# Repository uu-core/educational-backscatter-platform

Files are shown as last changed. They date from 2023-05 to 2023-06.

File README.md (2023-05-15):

# Pico-Backscatter
An educational project on backscatter using Raspberry Pi Pico

## Repo Organization
- `hardware` contains the hardware design with further description and explanation (generating the PIO using the python script).
- `project_pico_libs` contains the libs for all projects using the RPI Pico (carrier/receiver/baseband).
- `baseband` contains a 2-FSK baseband code using Pico PIO together with a generator script, its description and some exercise questions.
- `carrier-CC2500` contains a carrier generator using the Mikroe-1435 (CC2500) on the Pico.
- `receiver-CC2500` contains a receiver using the Mikroe-1435 (CC2500) on the Pico.
- `carrier-Firefly` contains the configuration guidance for home setup with zolertia firefly as carrier.
- `carrier-characteristics` contains a measurement to estimate the typical carrier bandwidth.
- `carrier_receiver-CC1352` contains the configuration guidance for lab setup with CC1352 as carrier and/or receiver.
- `carrier-receiver-baseband` integrates all components into one setup: the Pico generates the baseband, uses one Mikroe-1435 (CC2500) to generate a carrier and a second Mikroe-1435 (CC2500) to receive the backscattered signal.
- `stats` contains the system evaluation script.

## Installation
A number of pre-requisites are needed to work with this repo:
Raspberry Pi Pico SDK, cmake and arm-none-eabi-gcc have to be installed for building and flashing the application code.
<br>Please follow the installation guidance in [Getting started with Rasberry Pi Pico](https://datasheets.raspberrypi.com/pico/getting-started-with-pico.pdf).
<br>Using Visual Studio Code is recommended.

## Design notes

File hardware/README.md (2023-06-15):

# Pico-Backscatter: frontend
The implementation for the backscatter tag frontend on a four-layer FR4 PCB with 1oz copper thickness and a spacing of 0.2mm between the top and first inner layer for 50 ohm impedance matching.

### Usage notes
- The board can be used with the Maker Pi Pico (bottom connectors) or the Raspberry Pi Pico (top connectors). _Do not connect a RPI Pico and Maker Pi Pico at the same time._
- For power measurements, a power profiler can be connected to J5. Remember that the board should not be powered by two sources at the same time. Therefore, _unplug the USB from the RPI Pico before using an external power supply, such as a power profiler_. Just in case that two supplies get connected at the same time, they are be protected by a schottky diode. Therefore the board is supplied with about 0.25V less than provided (the voltage drop can be avoided by: supplying the voltage directly to the VSYS pin rather than J5, which avoids the diode and is therefore unprotected. Another alternative is to replace the diode with a mosfet in standard reverse voltage protection configuration).
- The board provides an interface to four SMA connectors for backscattering signals. This enables the use of antenna arrays and the resulting directivity/gain of different configurations can be generated using [Matlab's Antenna array design tool](https://se.mathworks.com/help/antenna/gs/design-and-analysis-using-antenna-array-designer-app.html).
- The board provides two connections for the ccRF click boards (Mikroe-1435 with the CC2500). They can be used as carrier generator and receiver.
- Notice that you can simulate a larger distance to the carrier by decreasing the transmission power in a static setup.

### Technical notes
- Each antenna is connected to an open or closed circuit based on a signal of the RPI Pico. This results in a reflection coefficient of +1 or -1, such that the incoming signal is always fully reflected either in phase (0°) or inverted (at 180° phase). In the time domain, we can think of this as taking the carrier and multiplying it with a sequence of +1/-1, which is equivalent to a convolution in the frequency domain and can therefore be used as modulation.
- Consider an ambient carrier signal $f_c$ and the RPI Pico generating a baseband signal $f_b$, which controls the antenna switch. The backscattered signal will then be $f_{s} = f_c + f_b$. Since we have control of $f_b$, we can use $f_s$ directly to generate a Frequency-Shift Keying (FSK) or On-Off Keying (OOK). Since additionally the phase of the carrier is static, the phase of the backscattered signal $f_s$ is equal to the phase of the baseband signal $f_b$. This can be used to generate a Phase-Shift Keying (PSK). For example, increasing the frequency of $f_b$ by 1 MHz and changing its phase by 90°, will also change the frequency and phase of the backscattered signal $f_s$ by 1 MHz and phase of 90°. Finally, due to the spectrum of a sinus, we obtain a second (mirrored) image of $f_s$ at $f_m = f_c - f_b$ which we can ignore for now. Since the baseband signal is also a square-wave and not a sinus, the backscattered signal will have harmonic overtones above $f_s$ and below $f_m$, which we can also ignore for now. However, you can find the mirrored image on the spectrum analyzer and also the overtones at a sufficiently large Signal-to-Noise ratio (SNR).
- The switch that controls the antenna termination could be implemented with a simple MOSFET. However, using an RF-switch provides a better impedance matching and control. Therefore, this platform uses the design of Ambuj Varshney and uses the [HMC190BMS8E](https://www.analog.com/media/en/technical-documentation/data-sheets/hmc190b.pdf). RF-switches can be categorized into having reflective (open circuit) or absorptive ($50 \Omega$ matching) inputs while not being selected to connect to the output. The HMC190BMS8E is a reflective RF-switch. Therefore, we can connect the antenna to its _input_. While the antenna is not selected as input, the RF-switch represents an open circuit (reflection coefficient +1). Now, we can terminate the output of the RF-switch directly to ground to generate the short circuit (reflection coefficient -1). The baseband signal of the RPI Pico controls if the antenna input connects to the output of the RF-switch or not and therefore changes the reflection coefficient at the antenna as described above between +1/-1.

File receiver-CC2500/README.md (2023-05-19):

# Pico-Backscatter: receiver-CC2500

### Decription
Receiver example using the Mikroe-1435 (CC2500) on the Pico.
The stdout (printf) has been directed to USB.

## Backscatter Tag Configuration
Please change the Macro variable RECEIVER to 2500.

### Radio wiring information

The example here uses SPI 0.

   * GPIO 17 (pin 22) Chip select
   * GPIO 18 (pin 24) SCK/spi0_sclk
   * GPIO 19 (pin 25) MOSI/spi0_tx
   * GPIO 21 GDO0: interrupt for received sync word

### Receiver configuration

The CC2500 can transmit and receive arbitrarily long packets. However, is FIFO is limited to 64 byte, out of which 4 byte are occupied by the length-field, sequence number and link quality information. This leaves 60 bytes for the payload.

To transmit larger payloads, it would be necessary to continoulsy empty the fifo while receiving a packet which can lead to unwanted and timing dependent byte duplications as highlighted in the [datasheet errata](https://www.ti.com/lit/er/swrz002e/swrz002e.pdf).

### Radio Settings
The radio settings and configuration can be generated using [SmartRF Studio](https://www.ti.com/tool/SMARTRFTM-STUDIO) and the datasheet of the corresponding module. Notice that the the configured baudrate of the Pico may be imprecise and differ from the one that the radio should be using. To export the register settings compatible with the provided examples, you can add a new template with the following settings (Register Export -> New ->):
- Header
    ```
    #ifndef RF_SETTING
    #define RF_SETTING
    struct rf_setting {
        uint8_t address;
        uint8_t  value;
    };
    typedef struct rf_setting RF_setting;
    #endif

    RF_setting radio_settings[] = {
    ```
- Body:
    ```
        {.address = 0x@ah@,@<<@ .value = 0x@VH@}, // @CHIPID@_@RN@: @Rd@
    ```
- Footer `};`

Additionally, notice that the exported register configuration of SmartRF Studio does not contain the transmission power setting, which is configured in the PA-Table.

### Build the project
Please follow the installation guidance in [Getting started with Raspberry Pi Pico](https://datasheets.raspberrypi.com/pico/getting-started-with-pico.pdf).

For **Linux and MacOS**:
1. set the sdk path {the path} with the absolute path\
```
 export PICO_SDK_PATH={the path}/pico-sdk
```
2. create build folder
```
mkdir build && cd build
```
3. prepare cmake build directory by running
```
cmake ..
```
4. build project
```
make
```

For **Windows**:
1. set the sdk path {the path} with the absolute path\
```
 setx PICO_SDK_PATH "{the path}/pico-sdk"
```
2. create build folder
```
mkdir build
cd build
```
3. prepare cmake build directory by running
```
cmake -G "NMake Makefiles" ..
nmake
```

## Reference
[Raspberry Pi Pico SDK Libraries and tools for C/C++ development on RP2040 microcontrollers](https://datasheets.raspberrypi.com/pico/raspberry-pi-pico-c-sdk.pdf).
<br>The details about PIO, please refer to [RP2040 Datasheet](https://datasheets.raspberrypi.com/rp2040/rp2040-datasheet.pdf).

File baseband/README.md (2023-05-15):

# Pico-Backscatter: baseband
The implementation for backscatter tag onboard control unit to generate an information-bearing 2-FSK signal using Raspberry Pi Pico PIO.
The stdout (printf) has been directed to USB.

## Repo Organization
- `generate-backscatter-pio.py` provides a script to generate a PIO file for the desired shift frequencies and baud-rate.
- `backscatter.pio` provides an example output of `generate-backscatter-pio.py`
- `backscatter.c` contains an example of generating a pseudorandom payload and using the generated backscatter driver
- `CMakeList.txt`

## Frame Structure
| Header {10B} | Random Payload {Max. 60B} |
<br>**Header structure**
<br>| Preamble {4B} | SYNC words {4B} | Frame length {1B} | Sequence number {1B} |
<br> **RX: CC2500**
<br> | 0xaa 0xaa 0xaa 0xaa | 0xd3 0x91 0xd3 0x91 | 0x00 | 0x00 |
<br> **RX: CC1312**
<br> | 0xaa 0xaa 0xaa 0xaa | 0x93 0x0b 0x51 0xde | 0x00 | 0x00 |
<br> Please change the Macro variable RECEIVER, depending on your receiver setup.
<br>**Random Payload structure**
<br>| Pseudo sequence {2B} | random number {Max. 58B, which is equal to 29*(16-bit random number)}

## Usage of the PIO generation script

The PIO file is generated based on two clock-dividers from 125 MHz and a baud-rate. Each clock divider provides a frequency offset from the carrier for one symbol. The script prints the required radio settings in terms of the resulting center frequency offset and frequency deviation.
- Help: `python generate-backscatter-pio.py --help`
- Generating a PIO file: `python generate-backscatter-pio.py clock-divider-Symbol-0 clock-divider-Symbol-1 baud-rate output-file`

Example: `python generate-backscatter-pio.py 20 18 100000 ./backscatter.pio`
- 20     => 125MHz/20 = 6.25 MHz frequency offset from carrier for symbol 0
- 18     => 125MHz/18 = 6.94 MHz frequency offset from carrier for symbol 1
- 100000 => 100 kBaud
- notice that the output file has to match with the `CMakeLists.txt`

## Exercises questions
1. Why shall be used only _even_ clock dividers for generating the baseband?
2. How do the two frequency dividers and the baudrate affect the signal-to-noise ratio (SNR)? To maximize the SNR, how should the frequency deviation be? How should the baudrate be? How should the frequency offset be (remember its relation to $N_0$ due to the self-interference)?
3. What is the relation between the two clock dividers to achieve the best possible deviation for a given offset frequency? This relation leaves one degree of freedom. Generate a table which provides the achievable offset frequencies (center) together with the most desirable frequency deviation.
5. Question 2 highlighted a trade-off and question 3 highlighted a dependence. Create a simulation to identify the ideal trade-off parameter (table from question 3) for a given baudrate. How dependent are your results on the assumed distances and carrier?
Notice that you know the worst case baseband spectrum from the baudrate, can estimate the carrier spectrum using the measurements in `carrier-characteristics` and can take reasonable assumptions for the path-loss model and RX filter response.
6. Generate an experimental setup to estimate remaining parameters and calibrate the simulation.
7. Knowing the SNR at the receiver, the used signal bandwidth and assuming an additive white Gaussian noise (AWGN) channel: What is the *channel capacity* of your occupied resources based on the Shannon–Hartley theorem?
8. Assume you would like to optimize your parameters to maximize the channel capacity. Do you come to the same conclusion like for optimizing the SNR? Why/Why not?

### Antenna characteristics:
- the provided antennas are [Molex 2128601001](https://www.molex.com/molex/products/part-detail/antennas/2128601001)
- a quick guide of trace antennas can be found [here](https://www.ti.com/lit/an/swra351b/swra351b.pdf), which provides links to the most commen pcb antennas such as the [SWRA117 and its characteristics](https://www.ti.com/lit/an/swra117d/swra117d.pdf).

## Build the project
For **Linux and MacOS**:
1. set the sdk path {the path} with the absolute path\
```
 export PICO_SDK_PATH={the path}/pico-sdk
```
2. create build folder
```
mkdir build && cd build
```
3. prepare cmake build directory by running
```
cmake ..
```
4. build project
```
make
```

For **Windows**:
1. set the sdk path {the path} with the absolute path\
```
 setx PICO_SDK_PATH "{the path}/pico-sdk"
```
2. create build folder
```
mkdir build && cd build
```
3. prepare cmake build directory by running
```
cmake -G "NMake Makefiles" ..
nmake
```

## Reference
[Raspberry Pi Pico SDK Libraries and tools for C/C++ development on RP2040 microcontrollers](https://datasheets.raspberrypi.com/pico/raspberry-pi-pico-c-sdk.pdf).
<br>The details about PIO, please refer to [RP2040 Datasheet](https://datasheets.raspberrypi.com/rp2040/rp2040-datasheet.pdf).

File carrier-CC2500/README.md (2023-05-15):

# Pico-Backscatter: carrier-CC2500
### Decription
Carrier generator using the Mikroe-1435 (CC2500) on the Pico.
The stdout (printf) has been directed to USB.
The carrier is configured for 2450 MHz by default.

### Radio wiring information

The example here uses SPI 0.

   * GPIO  5 Chip select
   * GPIO 18 SCK/spi0_sclk
   * GPIO 19 MOSI/spi0_tx

### Radio Settings
The radio settings and configuration can be generated using [SmartRF Studio](https://www.ti.com/tool/SMARTRFTM-STUDIO) and the datasheet of the corresponding module.
<br>Notice that the the configured baudrate of the Pico may be imprecise and differ from the one that the radio should be using. <br>To export the register settings compatible with the provided examples, you can add a new template with the following settings (Register Export -> New ->):
- Header
    ```
    #ifndef RF_SETTING
    #define RF_SETTING
    struct rf_setting {
        uint8_t address;
        uint8_t  value;
    };
    typedef struct rf_setting RF_setting;
    #endif

    RF_setting radio_settings[] = {
    ```
- Body:
    ```
        {.address = 0x@ah@,@<<@ .value = 0x@VH@}, // @CHIPID@_@RN@: @Rd@
    ```
- Footer `};`

Additionally, notice that the exported register configuration of SmartRF Studio does not contain the transmission power setting, which is configured in the PA-Table.

### Build the project
Please follow the installation guidance in [Getting started with Raspberry Pi Pico](https://datasheets.raspberrypi.com/pico/getting-started-with-pico.pdf).

For **Linux and MacOS**:
1. set the sdk path {the path} with the absolute path\
```
 export PICO_SDK_PATH={the path}/pico-sdk
```
2. create build folder
```
mkdir build && cd build
```
3. prepare cmake build directory by running
```
cmake ..
```
4. build project
```
make
```

For **Windows**:
1. set the sdk path {the path} with the absolute path\
```
 setx PICO_SDK_PATH "{the path}/pico-sdk"
```
2. create build folder
```
mkdir build && cd build
```
3. prepare cmake build directory by running
```
cmake -G "NMake Makefiles" ..
nmake
```

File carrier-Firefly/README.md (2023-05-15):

# Pico-Backscatter: carrier-Firefly
Guide to configure Firefly to generate a unmodulated carrier in the range of 2394MHz to 2507MHz.

You will control the board via serial port.

## Access Serial Port
<br> Install the python pyserial library:
```
 pip install pyserial
```
<br> Find the connected device port under /dev. 

Firefly should be connected to a usb port. The port name that appears
in your OS is OS- and machine-specific, but
most likely starts with "tty.usb". One way is to 
disconnect and reconnect Firefly, and see the new name that appears.
```
ls /dev/
```
<br> Access the device via serial port:
```
python3 -m serial.tools.miniterm [your-port] 115200
```

## Configuration Option
After connecting with pyserial, it is possible that what you type in the 
console are invisible. They however should work after you press enter.

If the board does not respond to commands below, press reset button on Firefly
(you should see "hello world"). 

Configure the frequency
```
 f {frequency}
```
Start the carrier generation
```
 a
```
Reset the Firefly with reset button or the following command
```
 r
```

Example: set the carrier to 2450MHz
```
 f 2450
 a
```

## Reference
[Zolertia Firefly Datasheet](https://github.com/Zolertia/Resources/blob/master/Firefly/Hardware/Revision%20A/Datasheets/ZOL-BO001-A2%20-%20Firefly%20revision%20A%20Datasheet%20v.1.0.0.pdf)

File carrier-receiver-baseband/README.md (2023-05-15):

# Pico-Backscatter: carrier-receiver-backscatter (CC2500)
### Description
The implementation of a backscatter tag onboard control unit to generate an information-bearing 2-FSK signal using Raspberry Pi Pico PIO. The setup uses one Mikroe-1435 (CC2500) to generate a carrier and a second Mikroe-1435 (CC2500) to receive the backscattered signal.
The stdout (printf) has been directed to USB.

The example integrates the baseband, carrier generation and receiver. For further information on each component, please see the README files in:
- `baseband`
- `carrier-CC2500`
- `receiver-CC2500`

### Radio Settings
The radio settings and configuration can be generated using [SmartRF Studio](https://www.ti.com/tool/SMARTRFTM-STUDIO) and the datasheet of the corresponding module.
<br>Notice that the the configured baudrate of the Pico may be imprecise and differ from the one that the radio should be using. <br>To export the register settings compatible with the provided examples, you can add a new template with the following settings (Register Export -> New ->):
- Header
    ```
    #ifndef RF_SETTING
    #define RF_SETTING
    struct rf_setting {
        uint8_t address;
        uint8_t  value;
    };
    typedef struct rf_setting RF_setting;
    #endif

    RF_setting radio_settings[] = {
    ```
- Body:
    ```
        {.address = 0x@ah@,@<<@ .value = 0x@VH@}, // @CHIPID@_@RN@: @Rd@
    ```
- Footer `};`

Additionally, notice that the exported register configuration of SmartRF Studio does not contain the transmission power setting, which is configured in the PA-Table.

### Build the project
Please follow the installation guidance in [Getting started with Raspberry Pi Pico](https://datasheets.raspberrypi.com/pico/getting-started-with-pico.pdf).

For **Linux and MacOS**:
1. set the sdk path {the path} with the absolute path\
```
 export PICO_SDK_PATH={the path}/pico-sdk
```
2. create build folder
```
mkdir build && cd build
```
3. prepare cmake build directory by running
```
cmake ..
```
4. build project
```
make
```

For **Windows**:
1. set the sdk path {the path} with the absolute path\
```
 setx PICO_SDK_PATH "{the path}/pico-sdk"
```
2. create build folder
```
mkdir build && cd build
```
3. prepare cmake build directory by running
```
cmake -G "NMake Makefiles" ..
nmake
```

## Reference
[Raspberry Pi Pico SDK Libraries and tools for C/C++ development on RP2040 microcontrollers](https://datasheets.raspberrypi.com/pico/raspberry-pi-pico-c-sdk.pdf).
<br>The details about PIO, please refer to [RP2040 Datasheet](https://datasheets.raspberrypi.com/rp2040/rp2040-datasheet.pdf).

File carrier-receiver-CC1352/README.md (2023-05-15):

# Pico-Backscatter: carrier-receiver-CC1352
The configuration for Firefly to generate a unmodulated carrier in the range of 2394MHz to 2507MHz.
Control the launchpad via SmartRF studio.

## Installation
SmartRF™ Studio is a **Windows** application that helps designers of RF systems to easily evaluate the radio at an early stage in the design process for all TI CC1xxx and CC2xxx low-power RF devices.
<br> Please follow the installation guidance on Texas Instrument webpage [SmartRF Studio](https://www.ti.com/tool/SMARTRFTM-STUDIO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,stage%20in%20the%20design%20process.)

## Carrier
In the control panel, choose `Continuous TX`, `Unmodulated`, `Frequency`, `Transmission power 0dBm`
<br>Then click `Start`.

## Packet Receiver
In the control panel, choose `2.4G frequency band`, `Packet RX`
<br>`Base Freqeuncy`: $f_{R}$
<br>`Data Rate`: $R_{b}$
<br>`Deviation`: $\delta_{FSK}$
<br>`RX Filter BW`: $B_{R}$
<br>`Viewing Format` : Hexadecimal
<br>`Seq. Number Included in Payload`: uncheck
<br>`Length Config`: fixed (set the number based on the frame size configured on tag), or variable (use the length field to decide the frame length)
<br>Then click `Start`

## A screenshot of the SmartRF configuration as receiver
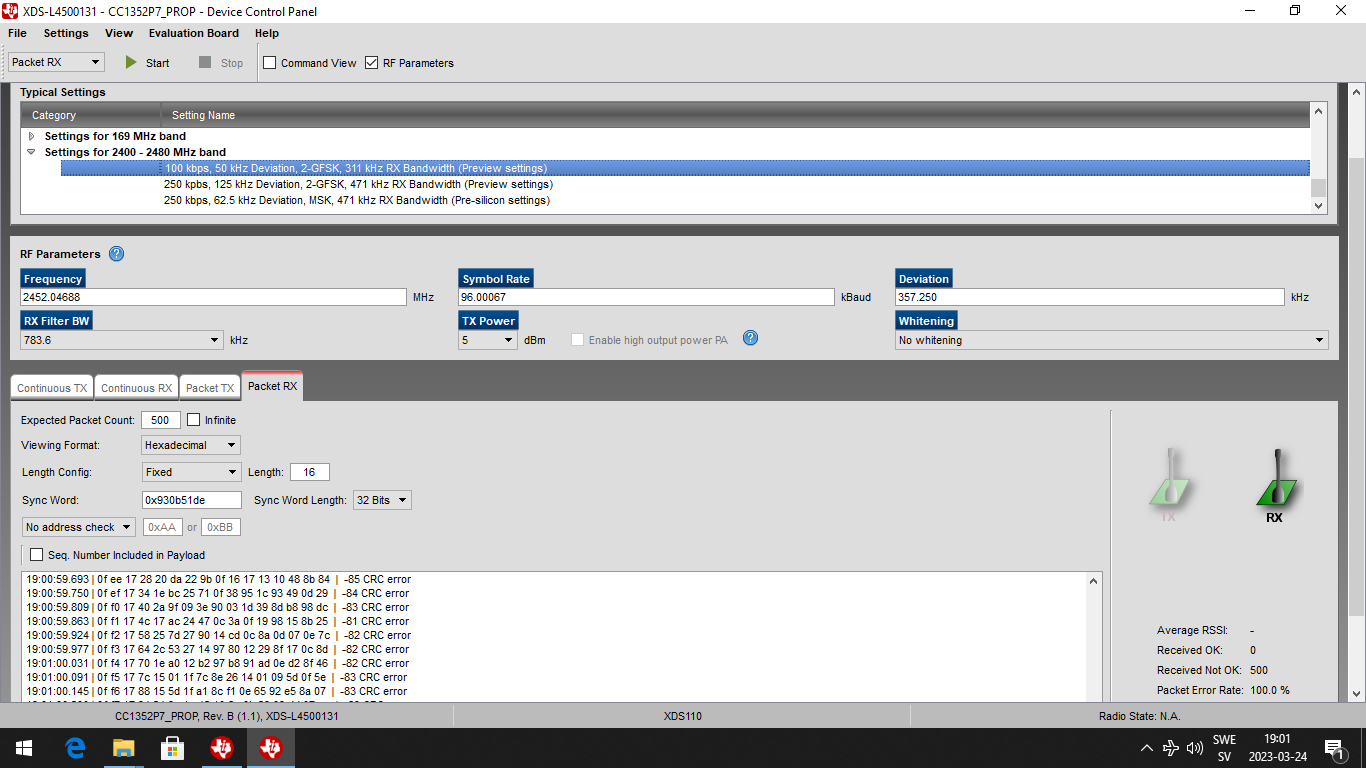
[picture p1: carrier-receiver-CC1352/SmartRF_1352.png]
plot

## Backscatter Tag Configuration
Please change the Macro variable RECEIVER to 1352.

## Reference
[CC1352P7 Datasheet](https://www.ti.com/product/CC1352P7)

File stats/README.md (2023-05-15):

# Pico-Backscatter: stats
A statistical analysis script evaluates communication system performance based on Jupyter Notebook.

## Evaluation metrics
- **Time**: the total latency that given amount of Data is delivered to the destination.
- **Reliability**: the ratio of data correctly delivered to the destination.
- **Distance Metric**: the communication distance of the system $D_{1}^2D_{2}^2$.

## Repo Organization
- `log.txt` contains log file received with either CC2500 or CC1352
- `functions.py` contains functions used in the analysis script
- `statistics.ipynb` contains the system evaluation script and visualisation script

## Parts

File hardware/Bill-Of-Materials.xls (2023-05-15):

Component | Order Qty. | Mouser No | Mfr. No | Manufacturer | Comment | Description
D1 | 1 | 863-MBR120VLSFT1G | MBR120VLSFT1G | onsemi | Polarity protection | Schottky Diodes & Rectifiers 1A 20V
C1-12 | 12 | 791-HH15N331F160CT | HH15N331F160CT | Walsin | RF Capacitors | Multilayer Ceramic Capacitors MLCC - SMD/SMT 0402 MLCC NPO 330 pF, +/- 1% 16 V T&R HH
J5 | 1 | 571-146280-2 | 146280-2 | TE Connectivity | - | Headers & Wire Housings 02 MODII HDR SRST B/A .100CL
U1-4 | 4 | 584-HMC190BMS8E | HMC190BMS8E | Analog Devices Inc. | - | RF Switch ICs Transmit/Receive (T/R) Switch, SPDT
R1-4 | 4 | 603-AT0402FRD071KL | AT0402FRD071KL | YAGEO | - | Thin Film Resistors - SMD 0402 1kOhms 1 % 25PPM 62.5mW AECQ200
AE1-4 | 4 | 710-60312002114503 | 60312002114503 | Wurth Elektronik | - | RF Connectors / Coaxial Connectors WR-SMA STRAIGHT JACK PCB THT
J1-4 | 4 | 200-SSM120FSV | SSM-120-F-SV | Samtec | Header Socket 1x20 SMD, 2.54mm pitch
J10-13 | 4 | 200-CES10801FS | CES-108-01-F-S | Samtec | Header Socket 1x08 Through Hole, 2.54mm pitch
J6-9 | - | (just drill holes) | - | - | - | -

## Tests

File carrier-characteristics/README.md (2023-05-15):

# Carrier characteristics

The provided images can be used to estimate the typical carrier bandwidth of the different nodes:
- the CC2500 was configured for a  $f_c=2450$ MHz carrier, had an error of $f_e = 0.12$ MHz and two side lobes at $\pm 1$ MHz. The combined bandwidth of all three lobes was ~2.5 MHz:
    - center: $(f_c + f_e)$ MHz
    - center bandwidth: ~1.078 MHz
    - right-lobe: $(f_c + f_e + 1)$ MHz
    - right-lobe bandwidth: ~0.520 MHz
    - left-lobe: $(f_c + f_e - 1)$ MHz
    - left-lobe bandwidth: ~0.520 MHz
- the CC1352P7 was configured for a $f_c=2455$ MHz carrier:
    - center: $f_c$ MHz
    - center bandwidth: ~1.158 MHz
- the Firefly was configured for a $f_c=2445$ MHz carrier
    - center: $f_c$ MHz
    - center bandwidth: ~0.918 MHz

## Center
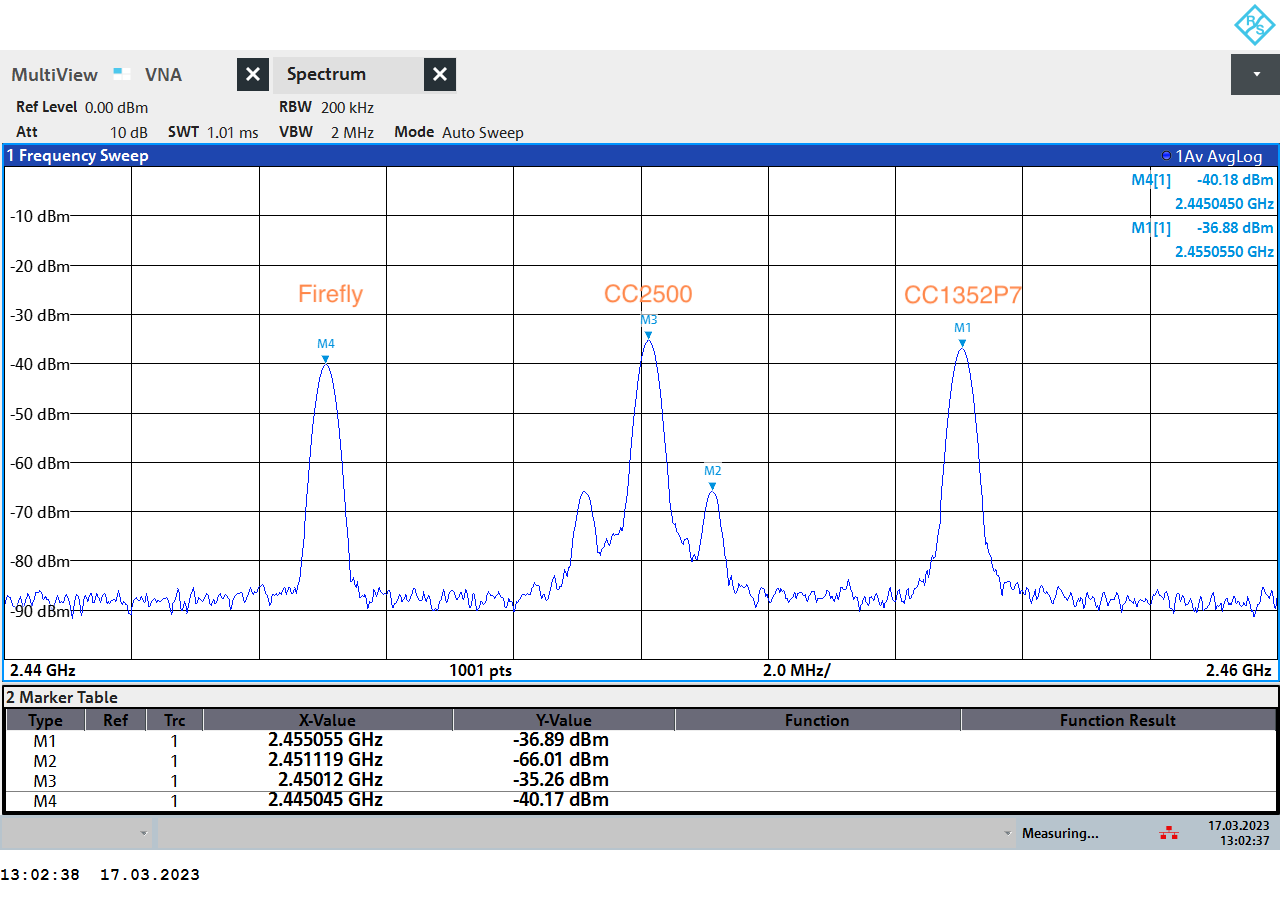
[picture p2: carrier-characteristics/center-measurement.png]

## Edge
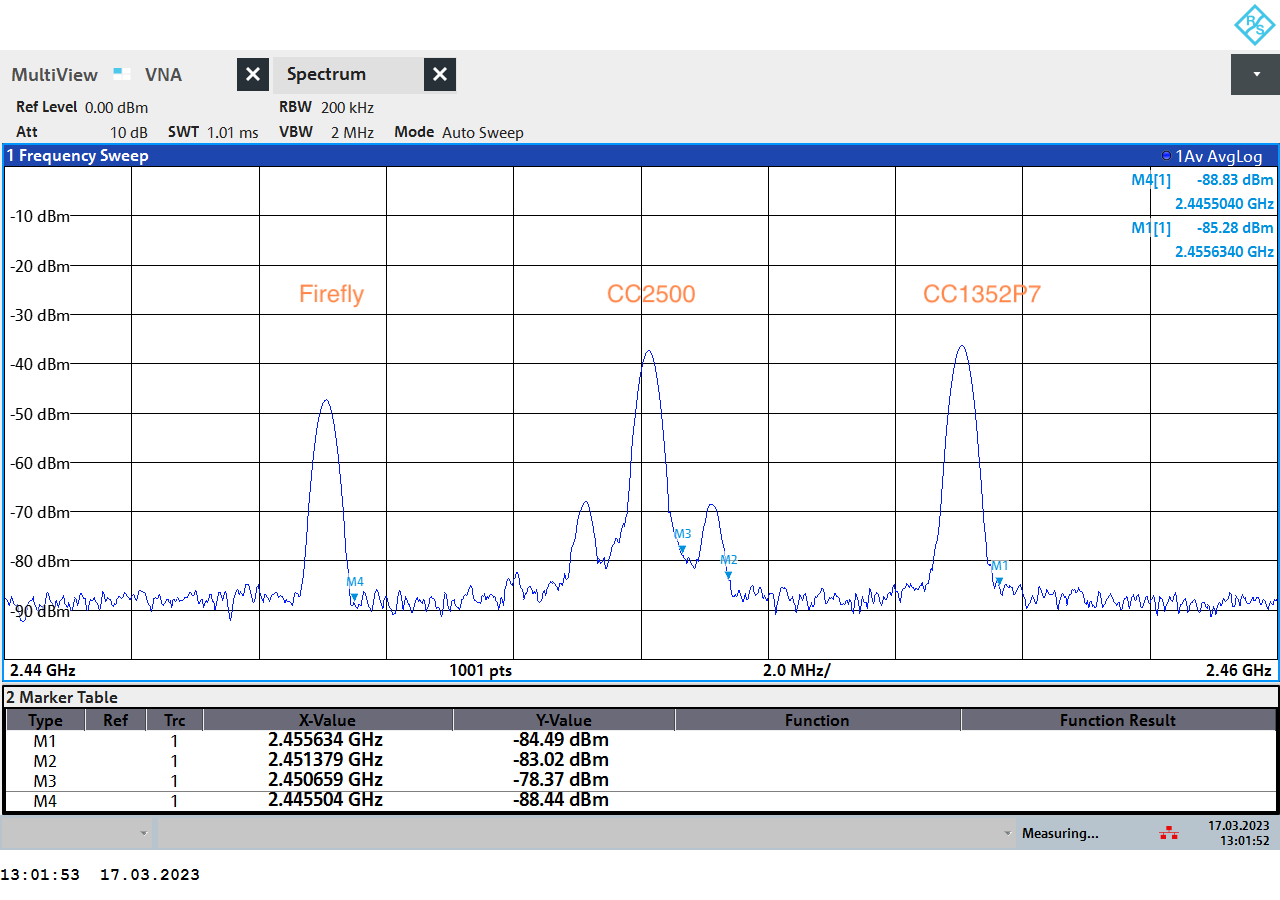
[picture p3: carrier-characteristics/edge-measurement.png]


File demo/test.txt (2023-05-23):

start listening
00:00:00.000 | 0f 00 a5 a5 a5 a5 a5 a5 a5 a5 a5 a5 a5 a5 a5 a5 | -62 CRC error 
00:00:01.000 | 0f 01 a5 a5 a5 a5 a5 a5 a5 a5 a5 a5 a5 a5 a5 a5 | -61 CRC error 
00:00:02.000 | 0f 02 a5 a5 a5 a5 a5 a5 a5 a5 a5 a5 a5 a5 a5 a5 | -61 CRC error 
00:00:03.000 | 0f 03 a5 a5 a5 a5 a5 a5 a5 a5 a5 a5 a5 a5 a5 a5 | -61 CRC error
00:00:04.000 | 0f 04 a5 a5 a5 a5 a5 a5 a5 a5 a5 a5 a5 a5 a5 a5 | -61 CRC error
00:00:05.000 | 0f 05 a5 a5 a5 a5 a5 a5 a5 a5 a5 a5 a5 a5 a5 a5 | -61 CRC error
00:00:06.000 | 01 01 a5 | -61 CRC error
00:00:07.000 | 0f 07 a5 a5 a5 a5 a5 a5 a5 a5 a5 a5 a5 a5 a5 a5 | -61 CRC error
00:00:08.000 | 0f 08 a5 a5 a5 a5 a5 a5 a5 a5 a5 a5 a5 a5 a5 a5 | -61 CRC error
00:00:09.000 | 0f 09 a5 a5 a5 a5 a5 a5 a5 a5 a5 a5 a5 a5 a5 a5 | -61 CRC error

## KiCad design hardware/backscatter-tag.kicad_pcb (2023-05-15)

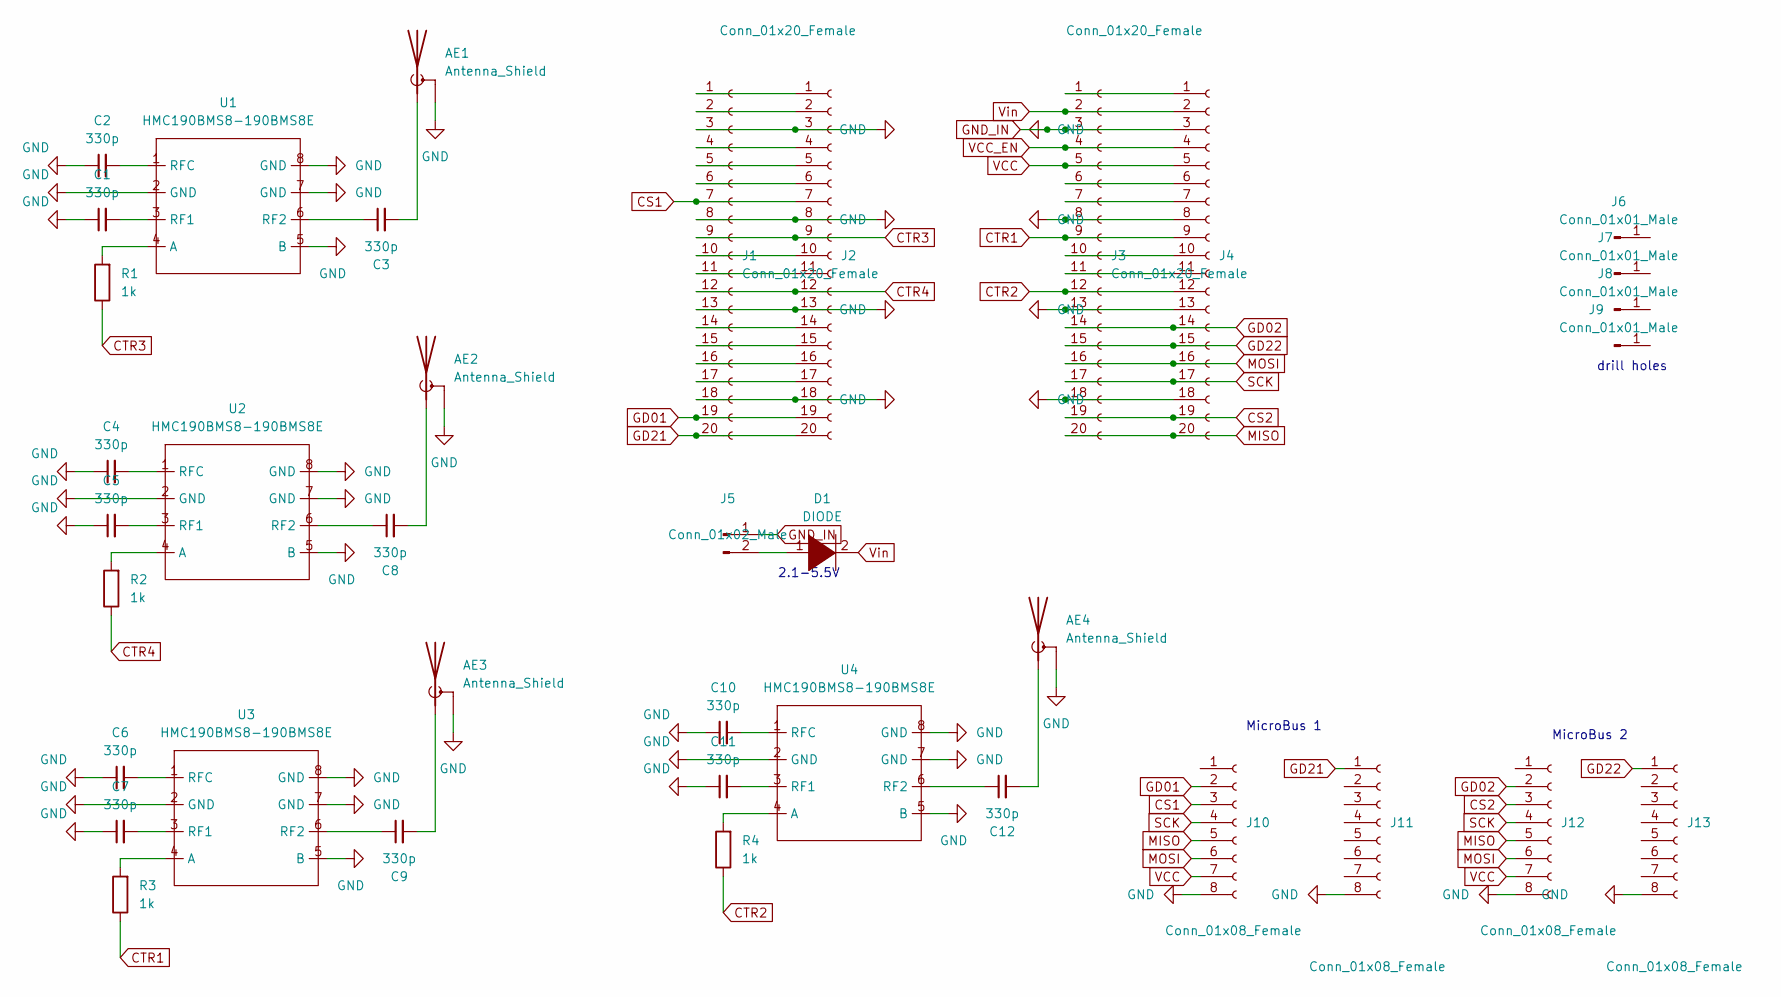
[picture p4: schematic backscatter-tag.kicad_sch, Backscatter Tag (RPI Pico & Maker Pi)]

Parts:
AE1, AE2, AE3, AE4: Antenna_Shield; SMA-60312002114503
C1, C2, C3, C4, C5, C6, C7, C8, C9, C10, C11, C12: 330p; C_0402_1005Metric
D1: DIODE; SOD-123FL-2
J1, J2, J3, J4: Conn_01x20_Female; PinSocket_1x20_P2.54mm_Vertical_SMD_Pin1Left
J5: Conn_01x02_Male; PinHeader_1x02_P2.54mm_Vertical
J6, J7, J8, J9: Conn_01x01_Male; mounting-whole
J10, J11, J12, J13: Conn_01x08_Female; PinSocket_1x08_P2.54mm_Vertical
R1, R2, R3, R4: 1k; R_0402_1005Metric
U1, U2, U3, U4: HMC190BMS8-190BMS8E; MSOP8

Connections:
CS1: J1.7, J2.7, J10.3
CS2: J3.19, J4.19, J12.3
CTR1: J3.9, J4.9, R3.1
CTR2: J3.12, J4.12, R4.1
CTR3: J1.9, J2.9, R1.1
CTR4: J1.12, J2.12, R2.1
GD01: J1.19, J2.19, J10.2
GD02: J3.14, J4.14, J12.2
GD21: J1.20, J2.20, J11.1
GD22: J3.15, J4.15, J13.1
GND_IN: AE1.2 (Shield), AE2.2 (Shield), AE3.2 (Shield), AE4.2 (Shield), C1.1, C2.1, C4.1, C5.1, C6.1, C7.1, C10.1, C11.1, J1.3, J1.8, J1.13, J1.18, J2.3, J2.8, J2.13, J2.18, J3.3, J3.8, J3.13, J3.18, J4.3, J4.8, J4.13, J4.18, J5.1, J10.8, J11.8, J12.8, J13.8, U1.2 (GND), U1.5 (B), U1.7 (GND), U1.8 (GND), U2.2 (GND), U2.5 (B), U2.7 (GND), U2.8 (GND), U3.2 (GND), U3.5 (B), U3.7 (GND), U3.8 (GND), U4.2 (GND), U4.5 (B), U4.7 (GND), U4.8 (GND)
MISO: J3.20, J4.20, J10.5, J12.5
MOSI: J3.16, J4.16, J10.6, J12.6
unnamed: AE1.1 (A), C3.2
unnamed: AE2.1 (A), C8.2
unnamed: AE3.1 (A), C9.2
unnamed: AE4.1 (A), C12.2
unnamed: C1.2, U1.3 (RF1)
unnamed: C2.2, U1.1 (RFC)
unnamed: C3.1, U1.6 (RF2)
unnamed: C4.2, U2.1 (RFC)
unnamed: C5.2, U2.3 (RF1)
unnamed: C6.2, U3.1 (RFC)
unnamed: C7.2, U3.3 (RF1)
unnamed: C8.1, U2.6 (RF2)
unnamed: C9.1, U3.6 (RF2)
unnamed: C10.2, U4.1 (RFC)
unnamed: C11.2, U4.3 (RF1)
unnamed: C12.1, U4.6 (RF2)
unnamed: D1.1 (K), J5.2
unnamed: J1.1, J2.1
unnamed: J1.2, J2.2
unnamed: J1.4, J2.4
unnamed: J1.5, J2.5
unnamed: J1.6, J2.6
unnamed: J1.10, J2.10
unnamed: J1.11, J2.11
unnamed: J1.14, J2.14
unnamed: J1.15, J2.15
unnamed: J1.16, J2.16
unnamed: J1.17, J2.17
unnamed: J3.1, J4.1
unnamed: J3.6, J4.6
unnamed: J3.7, J4.7
unnamed: J3.10, J4.10
unnamed: J3.11, J4.11
unnamed: R1.2, U1.4 (A)
unnamed: R2.2, U2.4 (A)
unnamed: R3.2, U3.4 (A)
unnamed: R4.2, U4.4 (A)
SCK: J3.17, J4.17, J10.4, J12.4
VCC: J3.5, J4.5, J10.7, J12.7
VCC_EN: J3.4, J4.4
Vin: D1.2 (A), J3.2, J4.2

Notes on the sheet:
MicroBus 1
drill holes
2.1-5.5V
MicroBus 2

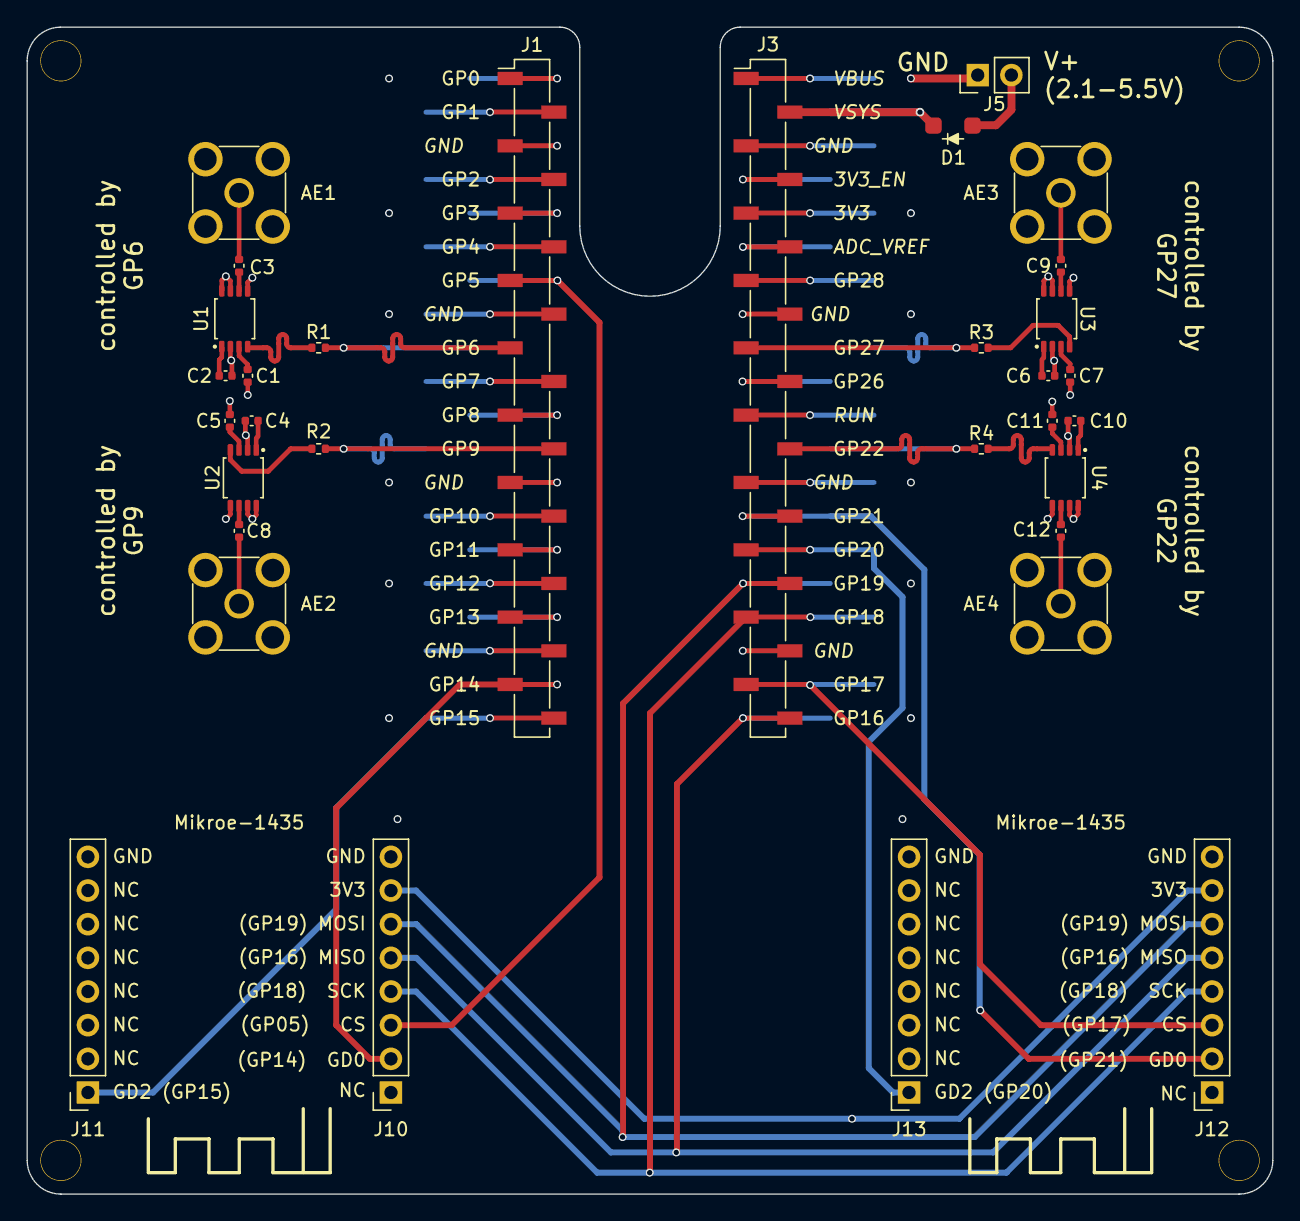
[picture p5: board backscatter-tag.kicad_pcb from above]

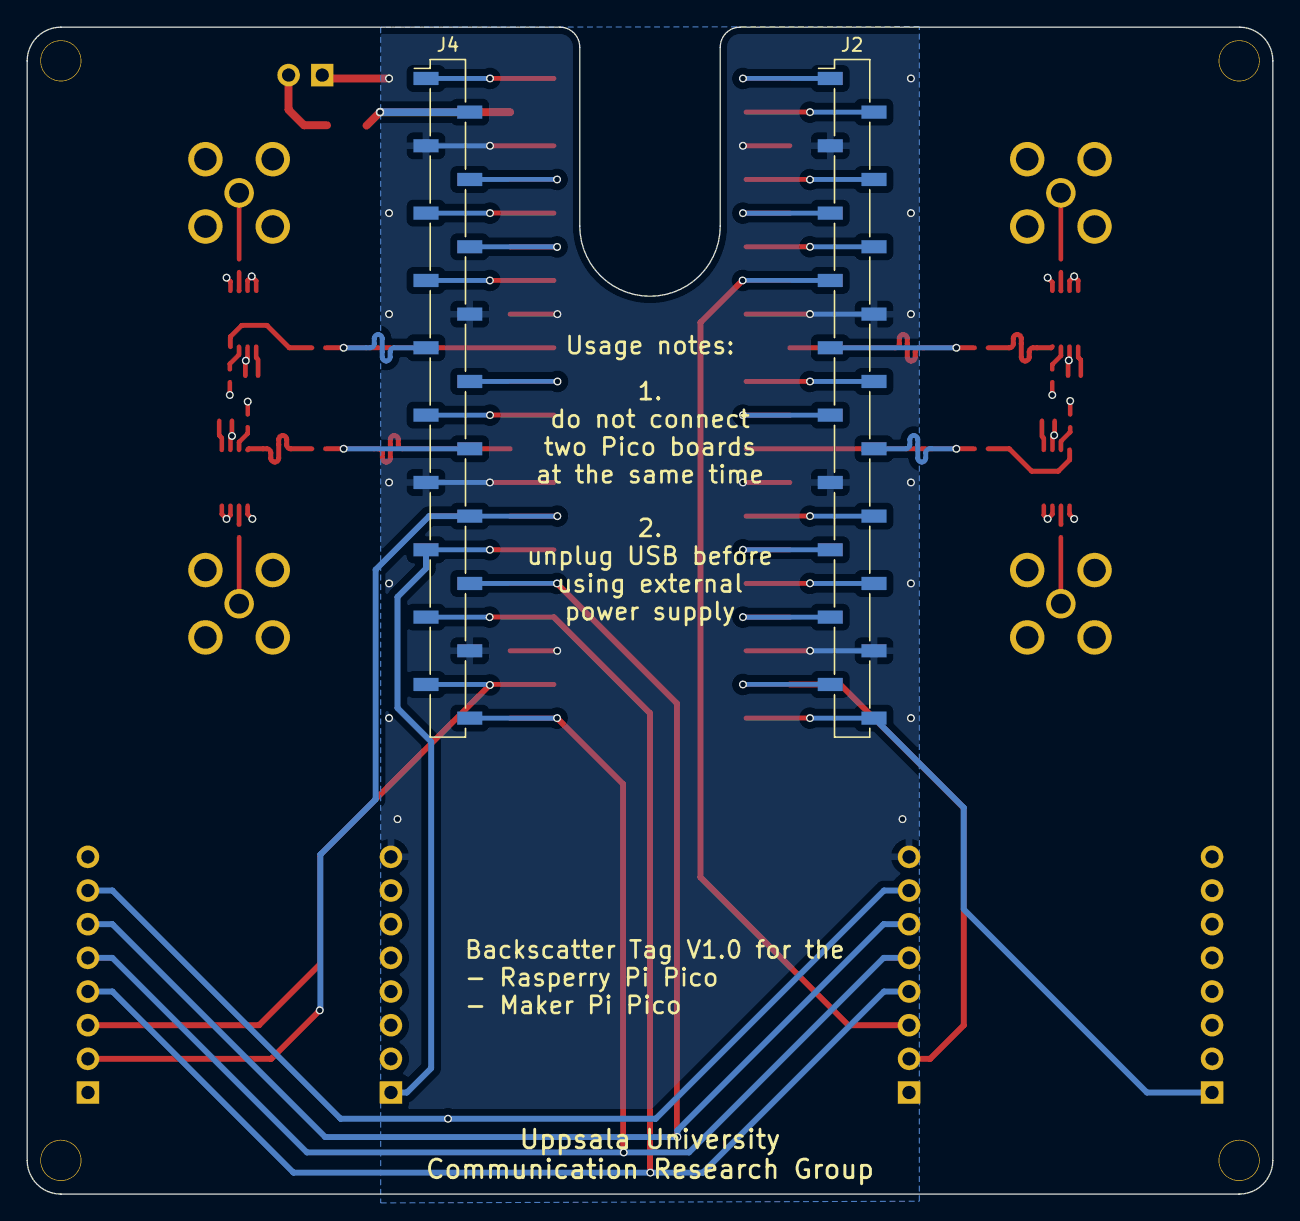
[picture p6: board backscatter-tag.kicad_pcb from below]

Board: 4 copper layers, 94.0 x 88.0 mm, 38 parts (2 on the bottom side), 54 nets.

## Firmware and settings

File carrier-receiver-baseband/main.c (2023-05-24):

/**
 * Tobias Mages & Wenqing Yan
 * Backscatter PIO
 * 02-March-2023
 *
 * See the sub-projects ... for further information:
 *  - baseband
 *  - carrier-CC2500
 *  - receiver-CC2500
 *
 */

#include <stdio.h>
#include <math.h>
#include <string.h>
#include "pico/stdlib.h"
#include "pico/sync.h"
#include "pico/multicore.h" 

#include "pico/util/queue.h"
#include "pico/binary_info.h"
#include "pico/util/datetime.h"
#include "hardware/spi.h"

#include "hardware/pio.h"
#include "hardware/clocks.h"
#include "command_receiver.h"
#include "backscatter.h"
#include "carrier_CC2500.h"
#include "receiver_CC2500.h"
#include "packet_generation.h"


#define RADIO_SPI             spi0
#define RADIO_MISO              16
#define RADIO_MOSI              19
#define RADIO_SCK               18

#define TX_DURATION            250 // send a packet every 250ms (when changing baud-rate, ensure that the TX delay is larger than the transmission time)
#define RECEIVER              2500 // define the receiver board either 2500 or 1352
#define PIN_TX1                  6
#define PIN_TX2                 27
#define CLOCK_DIV0              20 // larger
#define CLOCK_DIV1              18 // smaller
#define DESIRED_BAUD         50000
#define TWOANTENNAS           true

#define CARRIER_FEQ     2450000000

/* Event queue for commands (start/stop uses zero values) */

/* just for the printout below. not actually used*/
#define PIO_BAUDRATE 100000
#define PIO_CENTER_OFFSET 6597222
#define PIO_DEVIATION 347222
#define PIO_MIN_RX_BW 794444

uint32_t current_CENTER, current_DEVIATION, current_BAUDRATE, current_MIN_RX_BW, current_DIV0, current_DIV1, current_BAUD, current_DURATION;
mutex_t setting_mutex;

void do_commands(){
    command_struct cmd_event;
    if(queued_command()){
        if (get_command(&cmd_event)){
            switch (cmd_event.cmd){
                case 'e':
                    printf("The input was invalid. Enter 'h' for further information on the interface.\n");
                    break;
                case 'h':
                    printControlInfo();
                    break;
                case 's':
                    RX_start_listen();
                    break;
                case 't':
                    RX_stop_listen();
                    break;
                case 'c':
                    RX_stop_listen();
                    setupReceiver();
                    uint32_t conf_CENTER, conf_DEVIATION, conf_BAUDRATE, conf_MIN_RX_BW;
                    conf_CENTER = set_frecuency_rx(cmd_event.value1);
                    conf_DEVIATION = set_frequency_deviation_rx(cmd_event.value2);
                    conf_BAUDRATE = set_datarate_rx(cmd_event.value3);
                    conf_MIN_RX_BW = set_filter_bandwidth_rx(cmd_event.value4);
                    mutex_enter_blocking(&setting_mutex);
                    current_CENTER=conf_CENTER;
                    current_DEVIATION=conf_DEVIATION;
                    current_BAUDRATE=conf_BAUDRATE;
                    current_MIN_RX_BW=conf_MIN_RX_BW;
                    mutex_exit(&setting_mutex);
                    printf("Used configuration: c %u ", conf_CENTER);
                    printf("%u ", conf_DEVIATION);
                    printf("%u ", conf_BAUDRATE);
                    printf("%u\n", conf_MIN_RX_BW);
                    RX_start_listen();
                    break;
                case 'b':
                    printf("Changing pio-state machine...\n");
                    mutex_enter_blocking(&setting_mutex);
                    current_DIV0 = cmd_event.value1;
                    current_DIV1 = cmd_event.value2;
                    current_BAUD = cmd_event.value3;
                    mutex_exit(&setting_mutex);
                    PIO pio = pio0;
                    uint sm = 0;
                    struct backscatter_config backscatter_conf;
                    uint16_t instructionBuffer[32] = {0}; // maximal instruction size: 32
                    if(backscatter_program_init(pio, sm, PIN_TX1, PIN_TX2, cmd_event.value1, cmd_event.value2, cmd_event.value3, &backscatter_conf, instructionBuffer, TWOANTENNAS)){
                        printf("Pio-state machine successfully changed.\n");
                    }else{
                        printf("Issue encountered. The state-machine has not been updated.\n");
                    }
                    break;
                default:
                    printf("Invalid command obtained.\n");
                    break;
            }
        }
    }
}

int main() {
    /* setup SPI */
    stdio_init_all();
    // Setup USB input on second core
    mutex_init(&setting_mutex);
    mutex_enter_blocking(&setting_mutex);
    current_CENTER = CARRIER_FEQ + PIO_CENTER_OFFSET;
    current_DEVIATION = PIO_DEVIATION;
    current_BAUDRATE = PIO_BAUDRATE;
    current_MIN_RX_BW = PIO_MIN_RX_BW;
    current_DIV0 = CLOCK_DIV0;
    current_DIV1 = CLOCK_DIV1;
    current_BAUD = PIO_BAUDRATE;
    current_DURATION = TX_DURATION;
    mutex_exit(&setting_mutex);
    multicore_reset_core1(); 
    multicore_launch_core1(readInput_core1); 

    /* SPI setup */
    spi_init(RADIO_SPI, 5 * 1000000); // SPI0 at 5MHz.
    gpio_set_function(RADIO_SCK, GPIO_FUNC_SPI);
    gpio_set_function(RADIO_MOSI, GPIO_FUNC_SPI);
    gpio_set_function(RADIO_MISO, GPIO_FUNC_SPI);
    // Make the SPI pins available to picotool
    bi_decl(bi_3pins_with_func(RADIO_MOSI, RADIO_MISO, RADIO_SCK, GPIO_FUNC_SPI));

    // Chip select is active-low, so we'll initialise it to a driven-high state
    gpio_init(RX_CSN);
    gpio_set_dir(RX_CSN, GPIO_OUT);
    gpio_put(RX_CSN, 1);
    bi_decl(bi_1pin_with_name(RX_CSN, "SPI Receiver CS"));

    // Chip select is active-low, so we'll initialise it to a driven-high state
    gpio_init(CARRIER_CSN);
    gpio_set_dir(CARRIER_CSN, GPIO_OUT);
    gpio_put(CARRIER_CSN, 1);
    bi_decl(bi_1pin_with_name(CARRIER_CSN, "SPI Carrier CS"));

    sleep_ms(5000);

    /* setup backscatter state machine */
    PIO pio = pio0;
    uint sm = 0;
    struct backscatter_config backscatter_conf;
    uint16_t instructionBuffer[32] = {0}; // maximal instruction size: 32
    backscatter_program_init(pio, sm, PIN_TX1, PIN_TX2, CLOCK_DIV0, CLOCK_DIV1, DESIRED_BAUD, &backscatter_conf, instructionBuffer, TWOANTENNAS);

    static uint8_t message[buffer_size(PAYLOADSIZE+2, HEADER_LEN)*4] = {0};  // include 10 header bytes
    static uint32_t buffer[buffer_size(PAYLOADSIZE, HEADER_LEN)] = {0}; // initialize the buffer
    static uint8_t seq = 0;
    uint8_t *header_tmplate = packet_hdr_template(RECEIVER);
    uint8_t tx_payload_buffer[PAYLOADSIZE];

    /* Setup carrier */
    setupCarrier();
    set_frecuency_tx(CARRIER_FEQ);
    sleep_ms(1);

    /* Start Receiver */
    event_t evt = no_evt;
    Packet_status status;
    uint8_t rx_buffer[RX_BUFFER_SIZE];
    uint64_t time_us;
    setupReceiver();
    set_frecuency_rx(CARRIER_FEQ + backscatter_conf.center_offset);
    set_frequency_deviation_rx(backscatter_conf.deviation);
    set_datarate_rx(backscatter_conf.baudrate);
    set_filter_bandwidth_rx(backscatter_conf.minRxBw);
    sleep_ms(1);
    RX_start_listen();
    printf("started listening\n");
    bool rx_ready = true;

    printControlInfo();

    /* loop */
    absolute_time_t next_release_1 = delayed_by_ms(get_absolute_time(), TX_DURATION);
    absolute_time_t next_release_2 = delayed_by_ms(next_release_1, TX_DURATION);
    while (true) {
        while(absolute_time_diff_us(get_absolute_time(), next_release_1));
        next_release_1 = next_release_2;
        next_release_2 = delayed_by_ms(next_release_1, TX_DURATION);

        do_commands();
        evt = get_event();
        switch(evt){
            case rx_assert_evt:
                // started receiving
                rx_ready = false;
            break;
            case rx_deassert_evt:
                // finished receiving
                time_us = to_us_since_boot(get_absolute_time());
                status = readPacket(rx_buffer);
                printPacket(rx_buffer,status,time_us);
                RX_start_listen();
                sleep_ms(1);
                rx_ready = true;
            //break;   // don't break still transmit next packet
            case no_evt:
                // backscatter new packet if receiver is listening
                if (rx_ready){
                    /* generate new data */
                    // generate_data(tx_payload_buffer, PAYLOADSIZE, true);
                    for(uint8_t i = 0; i < PAYLOADSIZE; i++){
                        tx_payload_buffer[i] = 0xA5;                                    // FOR DEMO: fixed payload of 0xA5
                    }

                    /* add header (10 byte) to packet */
                    add_header(&message[0], 0xA5, header_tmplate);                      // FOR DEMO: fixed sequence number of 0xA5
                    /* add payload to packet */
                    memcpy(&message[HEADER_LEN], tx_payload_buffer, PAYLOADSIZE);

                    /* casting for 32-bit fifo */
                    for (uint8_t i=0; i < buffer_size(PAYLOADSIZE, HEADER_LEN); i++) {
                        buffer[i] = ((uint32_t) message[4*i+3]) | (((uint32_t) message[4*i+2]) << 8) | (((uint32_t) message[4*i+1]) << 16) | (((uint32_t)message[4*i]) << 24);
                    }
                    /* put the data to FIFO (start backscattering) */
                    startCarrier();
                    sleep_ms(1); // wait for carrier to start
                    backscatter_send(pio,sm,buffer,buffer_size(PAYLOADSIZE, HEADER_LEN));
                    sleep_ms(ceil((((double) buffer_size(PAYLOADSIZE, HEADER_LEN))*8000.0)/((double) DESIRED_BAUD))+3); // wait transmission duration (+3ms)
                    stopCarrier();
                    /* increase seq number*/ 
                    seq++;
                }
            break;
        }
    }

    /* stop carrier and receiver - never reached */
    RX_stop_listen();
    stopCarrier();
}

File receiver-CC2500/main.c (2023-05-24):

/**
 * Tobias Mages & Wenqing Yan
 *
 * Using the CC2500 to generate a 2450MHz unmodulated carrier with maximal output power of +1dBm.
 *
 * GPIO 17 (pin 22) Chip select
 * GPIO 18 (pin 24) SCK/spi0_sclk
 * GPIO 19 (pin 25) MOSI/spi0_tx
 * GPIO 21 GDO0: interrupt for received sync word
 *
 * The example uses SPI port 0.
 * The stdout has been directed to USB.
 *
 * The CC2500 can transmit and receive arbitrarily long packets. However, is FIFO is limited to 64 byte, 
 * out of which 4 byte are occupied by the length-field, sequence number and link quality information. 
 * This leaves 60 bytes for the payload.
 * To transmit larger payloads, it would be necessary to continoulsy empty the fifo while receiving a packet
 * which can lead to unwanted and timing dependent byte duplications as highlighted in the datasheet errata.
 * Therefore, we only start reading the fifo after the transmission is completed.
 *
 */
#include <stdio.h>
#include <string.h>
#include <stdint.h>
#include "pico/stdlib.h"
#include "pico/stdio_usb.h"
#include "pico/util/queue.h"
#include "pico/binary_info.h"
#include "hardware/spi.h"
#include "receiver_CC2500.h"
#include "pico/multicore.h" 

# define COMMAND_QUEUE_LENGTH 10

#define CARRIER_FEQ     2450000000
/* 
 * The following macros are defined in the generated PIO header file 
 * We define them here manually here since this example does not require a PIO state machine.
*/
#define PIO_BAUDRATE 100000
#define PIO_CENTER_OFFSET 6597222
#define PIO_DEVIATION 347222
#define PIO_MIN_RX_BW 794444

/* Event queue for commands (start/stop uses zero values) */
struct cmd_struct {
  char cmd;
  uint32_t  value1;
  uint32_t  value2;
  uint32_t  value3;
  uint32_t  value4;
};
typedef struct cmd_struct command_struct;
queue_t command_queue;

void printControlInfo(){
    printf("The configuration can be changed using the following commands:\n   h (print this help message)\n   s (start receiving)\n   t (terminate/stop receiving)\n   c A B C D (configure A=center, B=deviation, C=baud, D=bandswidth all in Hz)\n");
    printf("The initial configuration is:\n  c 2456597222 ");  // somehow the macro sum doesn't print here
    printf("%u ", PIO_DEVIATION);
    printf("%u ", PIO_BAUDRATE);
    printf("%u\n\n", PIO_MIN_RX_BW);
}

static char command[100];
static int buff_pos = 0;  

void readInput_core1(){
    while(true){
        /* read input, parse input and put commands into the command queue */
        int input = getchar();
        if ((input == '\n' || input == '\r' || input == EOF) && buff_pos > 0) {
            command[buff_pos] = '\0'; 

            /* parse input and put to queue */
            command_struct cmd_event;
            char cmd;
            uint32_t  value1, value2, value3, value4;
            if(sscanf(command, "%c %u %u %u %u", &cmd, &value1, &value2, &value3, &value4) != 5){
                if(sscanf(command, "%c", &cmd) != 1){
                    cmd_event.cmd = 'e'; // e for invalid input (error)
                    cmd_event.value1 = 0;
                    cmd_event.value2 = 0;
                    cmd_event.value3 = 0;
                    cmd_event.value4 = 0;
                    queue_try_add(&command_queue, &cmd_event);
                }else{
                    switch (cmd){
                        case 'h':
                            cmd_event.cmd = 'h';
                            cmd_event.value1 = 0;
                            cmd_event.value2 = 0;
                            cmd_event.value3 = 0;
                            cmd_event.value4 = 0;
                            queue_try_add(&command_queue, &cmd_event);
                            break;
                        case 's':
                            cmd_event.cmd = 's';
                            cmd_event.value1 = 0;
                            cmd_event.value2 = 0;
                            cmd_event.value3 = 0;
                            cmd_event.value4 = 0;
                            queue_try_add(&command_queue, &cmd_event);
                            break;
                        case 't':
                            cmd_event.cmd = 't';
                            cmd_event.value1 = 0;
                            cmd_event.value2 = 0;
                            cmd_event.value3 = 0;
                            cmd_event.value4 = 0;
                            queue_try_add(&command_queue, &cmd_event);
                            break;
                        default:
                            cmd_event.cmd = 'e'; // e for invalid input (error)
                            cmd_event.value1 = 0;
                            cmd_event.value2 = 0;
                            cmd_event.value3 = 0;
                            cmd_event.value4 = 0;
                            queue_try_add(&command_queue, &cmd_event);
                            break;
                    }
                }
            }else{
                switch (cmd){
                    case 'c':
                        cmd_event.cmd = 'c';
                        cmd_event.value1 = value1;
                        cmd_event.value2 = value2;
                        cmd_event.value3 = value3;
                        cmd_event.value4 = value4;
                        queue_try_add(&command_queue, &cmd_event);
                        break;
                    default:
                        cmd_event.cmd = 'e'; // e for invalid input (error)
                        cmd_event.value1 = 0;
                        cmd_event.value2 = 0;
                        cmd_event.value3 = 0;
                        cmd_event.value4 = 0;
                        queue_try_add(&command_queue, &cmd_event);
                        break;
                }
            }
            buff_pos = 0; 
        } else {
            command[buff_pos] = (char) input; 
            buff_pos++; 
        }
    }
}
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

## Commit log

2023-05-19 input callback not working
    [main.c, receiver_CC2500.c]
2023-05-19 working uart interface for dynamically changing baseband and receiver
2023-05-22 test logging and integrate receiver configuration into demo.py, use config.xlsx as configuration file
    [config.xlsx]
2023-05-23 add seq number, consider the missing packets in ber calculation
    [demo.py]
